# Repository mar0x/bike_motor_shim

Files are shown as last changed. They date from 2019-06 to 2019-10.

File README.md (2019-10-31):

# Shimano e-bike motor shim
Shimano e-bike shim between wheel sensor and motor to "extend the limits".

Attiny85 controller reads sensor pulses and adjust frequency to keep assist working.
Shim has relay for by-pass which is activated in absence of power. Most expensive part
is Shimano Di2 wire and Junction required for smooth connection.

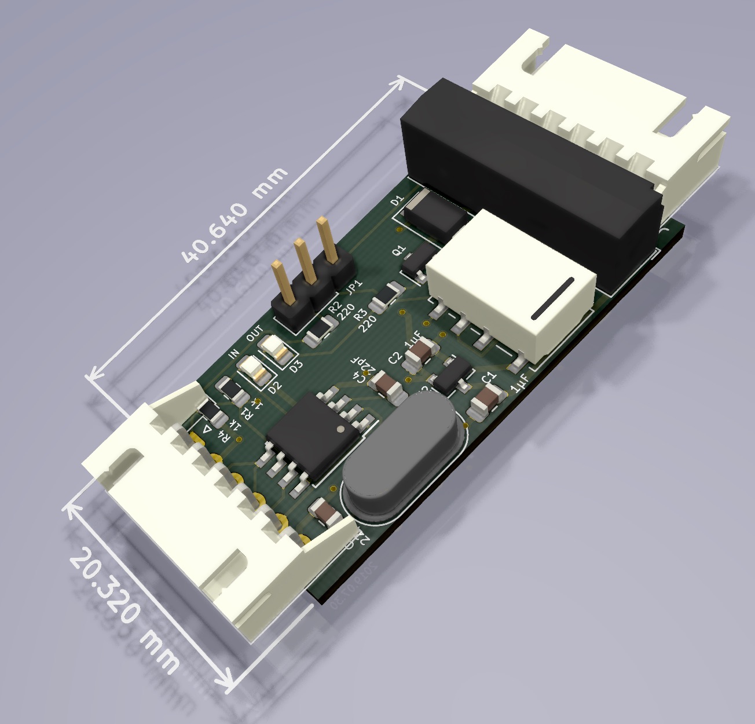
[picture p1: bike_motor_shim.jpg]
bike_motor_shim


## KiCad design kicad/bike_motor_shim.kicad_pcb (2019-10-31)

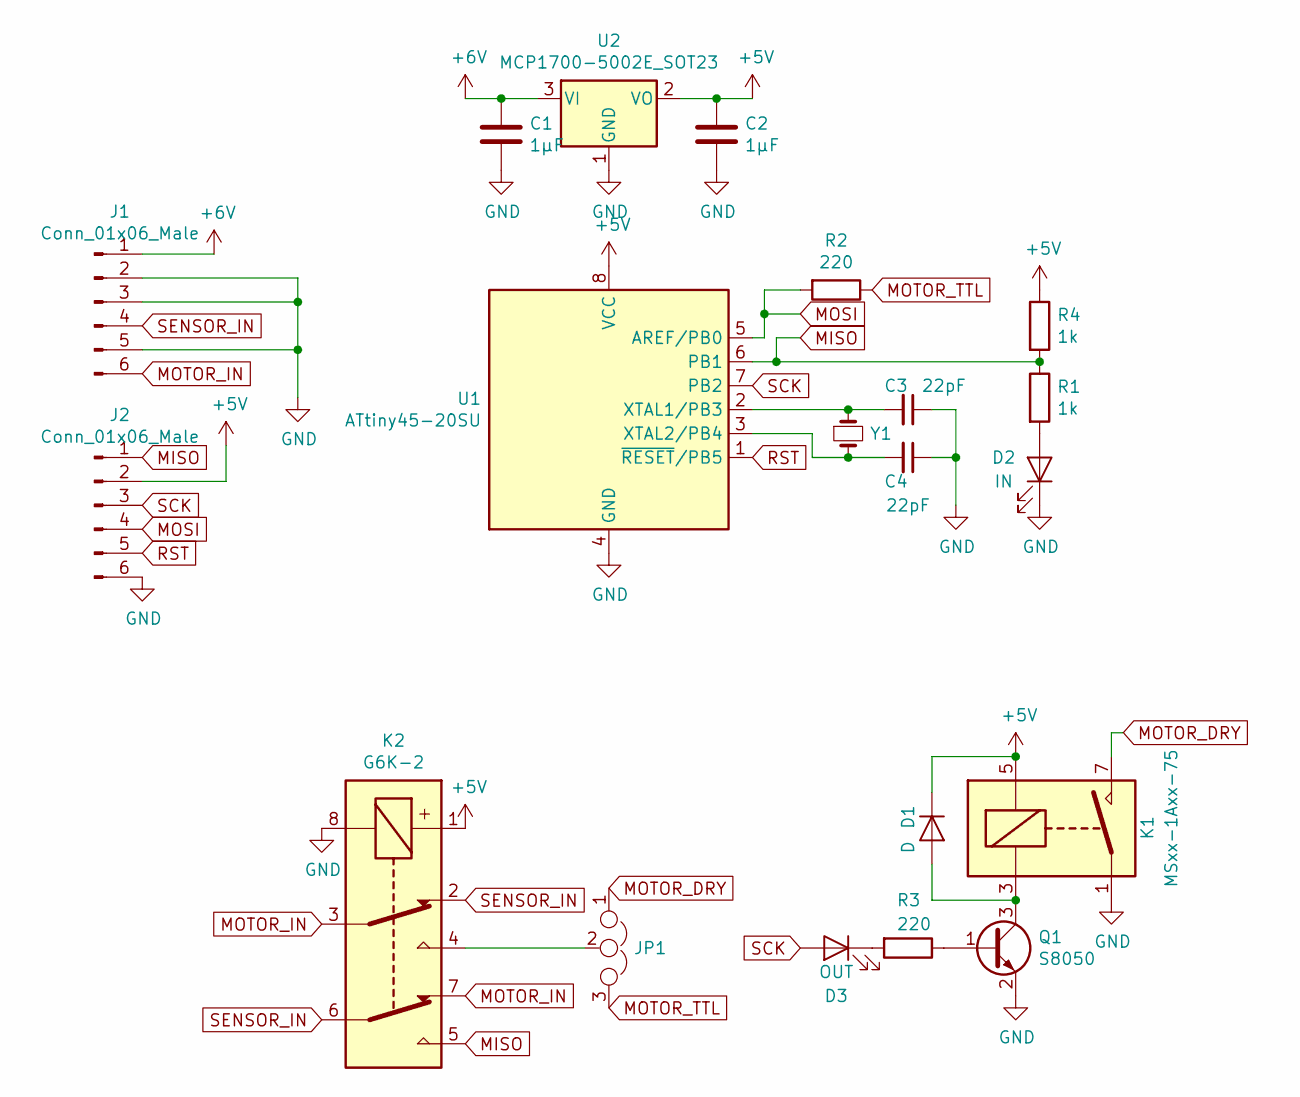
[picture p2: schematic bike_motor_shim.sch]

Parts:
C1, C2: 1µF; C_0805_2012Metric_Pad1.15x1.40mm_HandSolder
C3, C4: 22pF; C_0805_2012Metric_Pad1.15x1.40mm_HandSolder
D1: D; D_SMA
D2: IN; LED_0805_2012Metric_Pad1.15x1.40mm_HandSolder
D3: OUT; LED_0805_2012Metric_Pad1.15x1.40mm_HandSolder
J1, J2: Conn_01x06_Male; JST_XH_S06B-XH-A-1_1x06_P2.50mm_Horizontal
JP1: Jumper_NC_Dual; PinHeader_1x03_P2.54mm_Vertical
K1: MSxx-1Axx-75; Relay_SPST_StandexMeder_SIL_Form1A
K2: G6K-2; Relay_DPDT_Omron_G6K-2F-Y
Q1: S8050; SOT-23
R1, R4: 1k; R_0805_2012Metric_Pad1.15x1.40mm_HandSolder
R2, R3: 220; R_0805_2012Metric_Pad1.15x1.40mm_HandSolder
U1: ATtiny45-20SU; SOIJ-8_5.3x5.3mm_P1.27mm
U2: MCP1700-5002E_SOT23; SOT-23
Y1: Crystal_Small; Crystal_HC49-4H_Vertical

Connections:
+5V: C2.1, D1.1 (K), J2.2, K1.5, K2.1, R4.1, U1.8 (VCC), U2.2 (VO)
+6V: C1.1, J1.1, U2.3 (VI)
GND: C1.2, C2.2, C3.1, C4.1, D2.1 (K), J1.2, J1.3, J1.5, J2.6, K1.1, K2.8, Q1.2 (E), U1.4 (GND), U2.1 (GND)
MISO: J2.1, K2.5, R1.1, R4.2, U1.6 (PB1)
MOSI: J2.4, R2.2, U1.5 (AREF/PB0)
MOTOR_DRY: JP1.1, K1.7
MOTOR_IN: J1.6, K2.3, K2.7
MOTOR_TTL: JP1.3, R2.1
unnamed: C3.2, U1.2 (XTAL1/PB3), Y1.1
unnamed: C4.2, U1.3 (XTAL2/PB4), Y1.2
unnamed: D1.2 (A), K1.3, Q1.3 (C)
unnamed: D2.2 (A), R1.2
unnamed: D3.1 (K), R3.2
unnamed: JP1.2, K2.4
unnamed: Q1.1 (B), R3.1
RST: J2.5, U1.1 (~RESET~/PB5)
SCK: D3.2 (A), J2.3, U1.7 (PB2)
SENSOR_IN: J1.4, K2.2, K2.6

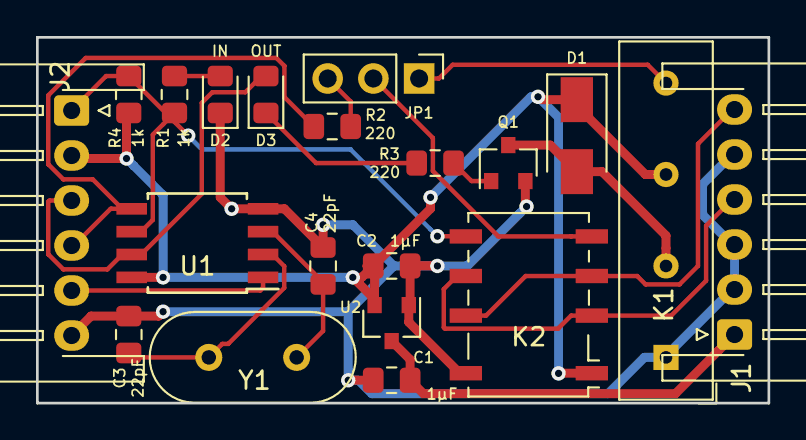
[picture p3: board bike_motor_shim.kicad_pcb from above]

Board: 2 copper layers, 40.6 x 20.3 mm, 20 parts (0 on the bottom side), 18 nets.

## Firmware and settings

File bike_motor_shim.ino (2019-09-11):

#include "artl/digital_in.h"
#include "artl/digital_out.h"
#include "artl/digital_pin.h"
#include "artl/pin_change_int.h"
#include "artl/yield.h"
#include "artl/button.h"


#if defined(__AVR_ATtiny25__) || defined(__AVR_ATtiny45__) || defined(__AVR_ATtiny85__)
#define SENSOR_IN_PIN   1
#define TTL_OUT_PIN     0
#define RELAY_OUT_PIN   2
#else
#define HAVE_HWSERIAL
#define SENSOR_IN_PIN   10
#define TTL_OUT_PIN     8
#define RELAY_OUT_PIN   9
#endif

#include "debug.h"

#define MAX_SPEED_KM_H        20
#define WHEEL_SIZE_INCH       27.5

#define MAX_SPEED_MM_S        ( ((unsigned long) MAX_SPEED_KM_H) * 1000 / 3.6 )
#define WHEEL_SIZE_MM         ( WHEEL_SIZE_INCH * 25.4 )
#define WHEEL_CIRC_MM         ( WHEEL_SIZE_MM * 3.14159265358 )
#define MAX_PULSE_FREQ        ( MAX_SPEED_MM_S / WHEEL_CIRC_MM )
#define MIN_PULSE_PERIOD_MS   ( 1000 / MAX_PULSE_FREQ )

const unsigned long min_period_ms = (unsigned long) MIN_PULSE_PERIOD_MS;

struct {
    using sensor_in = artl::digital_in<SENSOR_IN_PIN>;
    using sensor_int = artl::pin_change_int<sensor_in::pin>;

    unsigned long on_ms = 0;
    unsigned long pulse_ms = 1;
    unsigned long fixed_pulse_ms = 1;
    unsigned long period_ms = min_period_ms;
    unsigned long fixed_period_ms = min_period_ms;

    bool state = false;
    bool pulse = false;

    struct debouncer_traits {
        unsigned long bounce() const { return 2; }
        unsigned long hold() const { return 500; }
    };

    artl::button<artl::default_button_handler, debouncer_traits> debouncer;

    void setup() {
        sensor_in().setup();
        sensor_int().enable();
    }

    void on_change() {
    }

    void update(unsigned long t) {
        if (!debouncer.update(!sensor_in().read(), t)) {
            return;
        }

        bool new_state = debouncer.down();
        if (new_state == state) {
            return;
        }

        state = new_state;

        if (state) {
            pulse = true;

            period_ms = t - on_ms;
            if (period_ms < min_period_ms) {
                fixed_period_ms = 10 * period_ms * min_period_ms / (9 * period_ms + min_period_ms);
            } else {
                fixed_period_ms = period_ms;
            }
            on_ms = t;
            pulse_ms = 1;
        } else {
            if (t - on_ms > pulse_ms) {
                pulse_ms = t - on_ms;
            }
            if (pulse_ms == 0) {
                pulse_ms = 1;
            }
            fixed_pulse_ms = fixed_period_ms * pulse_ms / period_ms;
        }
    }
} sensor;

struct {
    using relay_out = artl::digital_out<RELAY_OUT_PIN>;
    using ttl_out = artl::digital_pin<TTL_OUT_PIN>;

    unsigned long on_ms = 0;

    bool state = false;

    void setup() {
        relay_out().setup();

        ttl_out().input();
    }

    void update(unsigned long t) {
        if (!state &&
            (sensor.state || (sensor.pulse && sensor.fixed_pulse_ms)) &&
            t - on_ms >= sensor.fixed_period_ms)
        {
            on(t);
            sensor.pulse = false;
        }

        if (state && sensor.fixed_pulse_ms &&
            t - on_ms >= sensor.fixed_pulse_ms)
        {
            off();
            sensor.fixed_pulse_ms = 0;
        }
    }

    void on(unsigned long t) {
        relay_out().high();

        ttl_out().output();
        ttl_out().low();

        state = true;
        on_ms = t;
    }

    void off() {
        relay_out().low();

        ttl_out().input();

        state = false;
    }

} relay;


#if defined(ISR) && defined(PCINT0_vect)
ISR(PCINT0_vect) {
    sensor.on_change();
}
#endif

void setup() {
#if defined(HAVE_HWSERIAL)
    Serial.begin(115200);
#endif

    sensor.setup();
    relay.setup();

//    artl::yield();
}

void loop() {
    unsigned long t = millis();

    sensor.update(t);
    relay.update(t);

//    artl::yield();
}

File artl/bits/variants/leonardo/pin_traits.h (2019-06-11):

#pragma once

namespace artl {

namespace pin {
    namespace id {
        enum {
            pd2   = 0,
            rxd1  = 0,
            pd3   = 1,
            pd1   = 2,
            sda   = 2,
            pd0   = 3,
            oc0b  = 3,
            scl   = 3,
            pd4   = 4,
            a6    = 4,
            pc6   = 5,
            oc3a  = 5,
            oc4a_ = 5,
            pd7   = 6,
            a7    = 6,
            oc4d  = 6,
            pe6   = 7,
            pb4   = 8,
            a8    = 8,
            pb5   = 9,
            a9    = 9,
            oc1a  = 9,
            adc12 = 9,
            oc4b_ = 9,
            pb6   = 10,
            a10   = 10,
            oc1b  = 10,
            adc13 = 10,
            oc4b  = 10,
            pb7   = 11,
            oc0a  = 11,
            oc1c  = 11,
            rts_  = 11,
            pd6   = 12,
            a11   = 12,
            oc4d_ = 12,
            adc9  = 12,
            t1    = 12,
            pc7   = 13,
            oc4a  = 13,
            icp3  = 13,
            clko  = 13,
            led   = 13,
/*
            pf7   = 14,
            a0    = 14,
            adc7  = 14,
            tdi   = 14,
            pf6   = 15,
            a1    = 15,
            adc6  = 15,
            tdo   = 15,
            pf5   = 16,
            a2    = 16,
            adc5  = 16,
            tms   = 16,
            pf4   = 17,
            a3    = 17,
            adc4  = 17,
            tck   = 17,
*/
            pf7   = 18,
            a0    = 18,
            pf6   = 19,
            a1    = 19,
            pf5   = 20,
            a2    = 20,
            pf4   = 21,
            a3    = 21,
            pf1   = 22,
            a4    = 22,
            pf0   = 23,
            a5    = 23,

            micro_14 = 14,   mini_12 = micro_14,
            micro_15 = 15,   mini_13 = micro_15,
            micro_16 = 16,   mini_11 = micro_16,
            micro_18 = 18,   mini_14 = micro_18,
            micro_19 = 19,   mini_15 = micro_19,
            micro_20 = 20,   mini_16 = micro_20,
            micro_21 = 21,   mini_17 = micro_21,
        };
    }

    using oc0a = pin_traits<id::oc0a>;
    using oc0b = pin_traits<id::oc0b>;

    using oc1a = pin_traits<id::oc1a>;
    using oc1b = pin_traits<id::oc1b>;

    using oc4a = pin_traits<id::oc4a>;
    using oc4b = pin_traits<id::oc4b>;
    using oc4d = pin_traits<id::oc4d>;
};

template<>
struct pin_traits<0> : public base_pin_traits<port::D, 2> { };

template<>
struct pin_traits<1> : public base_pin_traits<port::D, 3> { };

template<>
struct pin_traits<2> : public base_pin_traits<port::D, 1> { };

template<>
struct pin_traits<3> : public base_pin_traits<port::D, 0> { };

template<>
struct pin_traits<4> : public base_pin_traits<port::D, 4> { };

template<>
struct pin_traits<5> : public base_pin_traits<port::C, 6> { };

template<>
struct pin_traits<6> : public base_pin_traits<port::D, 7> { };

template<>
struct pin_traits<7> : public base_pin_traits<port::E, 6> { };

template<>
struct pin_traits<8> : public base_pin_traits<port::B, 4> { };

template<>
struct pin_traits<9> : public base_pin_traits<port::B, 5> { };

template<>
struct pin_traits<10> : public base_pin_traits<port::B, 6> { };

template<>
struct pin_traits<11> : public base_pin_traits<port::B, 7> { };

template<>
struct pin_traits<12> : public base_pin_traits<port::D, 6> { };

template<>
struct pin_traits<13> : public base_pin_traits<port::C, 7> { };

template<>
struct pin_traits<14> : public base_pin_traits<port::B, 3> { };

template<>
struct pin_traits<15> : public base_pin_traits<port::B, 1> { };

template<>
struct pin_traits<16> : public base_pin_traits<port::B, 2> { };

template<>
struct pin_traits<17> : public base_pin_traits<port::B, 0> { };

template<>
struct pin_traits<18> : public base_pin_traits<port::F, 7> { };

template<>
struct pin_traits<19> : public base_pin_traits<port::F, 6> { };

template<>
struct pin_traits<20> : public base_pin_traits<port::F, 5> { };

template<>
struct pin_traits<21> : public base_pin_traits<port::F, 4> { };

template<>
struct pin_traits<22> : public base_pin_traits<port::F, 1> { };

template<>
struct pin_traits<23> : public base_pin_traits<port::F, 0> { };

template<>
struct pin_traits<24> : public base_pin_traits<port::D, 4> { };

template<>
struct pin_traits<25> : public base_pin_traits<port::D, 7> { };

template<>
struct pin_traits<26> : public base_pin_traits<port::B, 4> { };

template<>
struct pin_traits<27> : public base_pin_traits<port::B, 5> { };

template<>
struct pin_traits<28> : public base_pin_traits<port::B, 6> { };

template<>
struct pin_traits<29> : public base_pin_traits<port::D, 6> { };

template<>
struct pin_traits<30> : public base_pin_traits<port::D, 5> { };

}

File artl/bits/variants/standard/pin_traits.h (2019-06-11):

#pragma once

namespace artl {

namespace pin {
    namespace id {
        enum {
            pd0   = 0,
            rxd   = 0,
            rx    = 0,
            pd1   = 1,
            txd   = 1,
            tx    = 1,
            pd2   = 2,
            int0  = 2,
            pd3   = 3,
            int1  = 3,
            oc2b  = 3,
            pd4   = 4,
            t0    = 4,
            xck   = 4,
            pd5   = 5,
            t1    = 5,
            oc0b  = 5,
            pd6   = 6,
            ain0  = 6,
            oc0a  = 6,
            pd7   = 7,
            ain1  = 7,
            pb0   = 8,
            clko  = 8,
            icp1  = 8,
            pb1   = 9,
            oc1a  = 9,
            pb2   = 10,
            oc1b  = 10,
            ss_   = 10,
            pb3   = 11,
            oc2   = 11,
            mosi  = 11,
            pb4   = 12,
            miso  = 12,
            pb5   = 13,
            sck   = 13,

            pc0   = 14,
            a0    = 14,
            adc0  = 14,
            pc1   = 15,
            a1    = 15,
            adc1  = 15,
            pc2   = 16,
            a2    = 16,
            adc2  = 16,
            pc3   = 17,
            a3    = 17,
            adc3  = 17,
            pc4   = 18,
            a4    = 18,
            adc4  = 18,
            sda   = 18,
            pc5   = 19,
            a5    = 19,
            adc5  = 19,
            scl   = 19,

            micro_14 = 12,   mini_12 = micro_14,
            micro_15 = 13,   mini_13 = micro_15,
            micro_16 = 11,   mini_11 = micro_16,
            micro_18 = 14,   mini_14 = micro_18,
            micro_19 = 15,   mini_15 = micro_19,
            micro_20 = 16,   mini_16 = micro_20,
            micro_21 = 17,   mini_17 = micro_21,
        };
    }

    using oc0a = pin_traits<id::oc0a>;
    using oc0b = pin_traits<id::oc0b>;

    using oc1a = pin_traits<id::oc1a>;
    using oc1b = pin_traits<id::oc1b>;
};

template<>
struct pin_traits<0> : public base_pin_traits<port::D, 0> { };

template<>
struct pin_traits<1> : public base_pin_traits<port::D, 1> { };

template<>
struct pin_traits<2> : public base_pin_traits<port::D, 2> { };

template<>
struct pin_traits<3> : public base_pin_traits<port::D, 3> { };

template<>
struct pin_traits<4> : public base_pin_traits<port::D, 4> { };

template<>
struct pin_traits<5> : public base_pin_traits<port::D, 5> { };

template<>
struct pin_traits<6> : public base_pin_traits<port::D, 6> { };

template<>
struct pin_traits<7> : public base_pin_traits<port::D, 7> { };

template<>
struct pin_traits<8> : public base_pin_traits<port::B, 0> { };

template<>
struct pin_traits<9> : public base_pin_traits<port::B, 1> { };

template<>
struct pin_traits<10> : public base_pin_traits<port::B, 2> { };

template<>
struct pin_traits<11> : public base_pin_traits<port::B, 3> { };

template<>
struct pin_traits<12> : public base_pin_traits<port::B, 4> { };

template<>
struct pin_traits<13> : public base_pin_traits<port::B, 5> { };

template<>
struct pin_traits<14> : public base_pin_traits<port::C, 0> { };

template<>
struct pin_traits<15> : public base_pin_traits<port::C, 1> { };

template<>
struct pin_traits<16> : public base_pin_traits<port::C, 2> { };

template<>
struct pin_traits<17> : public base_pin_traits<port::C, 3> { };

template<>
struct pin_traits<18> : public base_pin_traits<port::C, 4> { };

template<>
struct pin_traits<19> : public base_pin_traits<port::C, 5> { };

}

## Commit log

2019-06-28 PCB prototype
    [bike_motor_shim-B.Cu.gbr, bike_motor_shim-B.Mask.gbr, bike_motor_shim-B.Paste.gbr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]
2019-06-28 Fixed relay footprint
    [bike_motor_shim-B.Cu.gbr, bike_motor_shim-B.Mask.gbr, bike_motor_shim-B.Paste.gbr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]
2019-06-28 Fixing relay on/off conditions
    [bike_motor_shim.ino]
2019-06-28 Using button debouncer.
2019-07-07 Adding bypass relay and LEDs.
    [bike_motor_shim-B.Cu.gbr, bike_motor_shim-B.Mask.gbr, bike_motor_shim-B.Paste.gbr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]
2019-07-26 Fixing traces.
    Adding missed trace and increasing width of ground and power traces.
    [bike_motor_shim.kicad_pcb]
2019-07-26 Adapting code for updated board.
    Sensor on is externally pulled-up, sensor out transformed to experimental
    TTL output.
2019-08-10 Board and sketch improvements.
    [bike_motor_shim-B.Cu.gbr, bike_motor_shim-B.Mask.gbr, bike_motor_shim-B.Paste.gbr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]
2019-09-11 Adjusting debouncer and fixing pulse width reset.
    [bike_motor_shim.ino]
2019-10-31 Adding dimensions.
    [bike_motor_shim.kicad_pcb]
